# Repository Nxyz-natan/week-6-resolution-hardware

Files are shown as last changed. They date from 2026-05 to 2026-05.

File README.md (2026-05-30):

# RP2350A IMU Dev Board

A custom dev board built around the RP2350A microcontroller with an 
onboard MPU-6050 IMU for motion sensing, housed in a custom 3D printed case.

PCB Render:Screenshot 2026-05-29 at 9 38 06 PM

## How it works

The board uses a USB-C connector and an AMS1117-33 LDO to regulate 
5V down to 3.3V. The RP2350A runs with a 12MHz crystal oscillator and 
W25Q128 flash memory over QSPI. The MPU-6050 IMU connects over I2C on 
GPIO4 and GPIO5 for motion sensing. GPIO headers expose the remaining 
pins for external use.

KiCanvas Link: https://kicanvas.org/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

Case Design Link: https://app.shapr3d.com/p/ce0b803e-1716-4454-bb49-c60d17f44aa6

## Schematic

Schematic: Screenshot 2026-05-29 at 9 38 57 PM

## PCB

PCB: Screenshot 2026-05-29 at 9 39 11 PM

## Case

Case: Screenshot 2026-05-29 at 9 39 25 PM

## Bill of Materials

| Ref | Value  LCSC # |
|-----|---|
| U1 | RP2350A | C42411118 |
| U2 | W25Q128JVSIQ | C97521 |
| U3 | AMS1117-3.3 | C6186 |
| U4 | MPU-6050 | C24112 |
| R1, R2 | 5.1k 0603 | C2907044 |
| R3 | 1k 0603 | C22548 |
| R4, R5 | 27Ω 0603 | C137753 |
| R6, R7 | 10k 0603 | TBD |
| R8, R9 | 4.7k 0603 | C99782 |
| C1-C4 | 1uF 0603 | C15849 |
| C5-C11, C14-C18 | 100nF 0603  | C14663 |
| C12, C13 | 15pF 0603 | C1644 |
| Y1 | 12MHz Crystal SMD3225 | C9002 |
| J1 | USB-C TYPE-C-31-M-12 | C165948 |
| J2 | 1x04 Pin Header 2.54mm | C52016392 |
| J4 | 1x20 Pin Header 2.54mm | C50981 |
| J5 | 1x13 Pin Header 2.54mm  | C42372505 |
| SW1, SW2 | SW Push 6x6mm | C318884 |

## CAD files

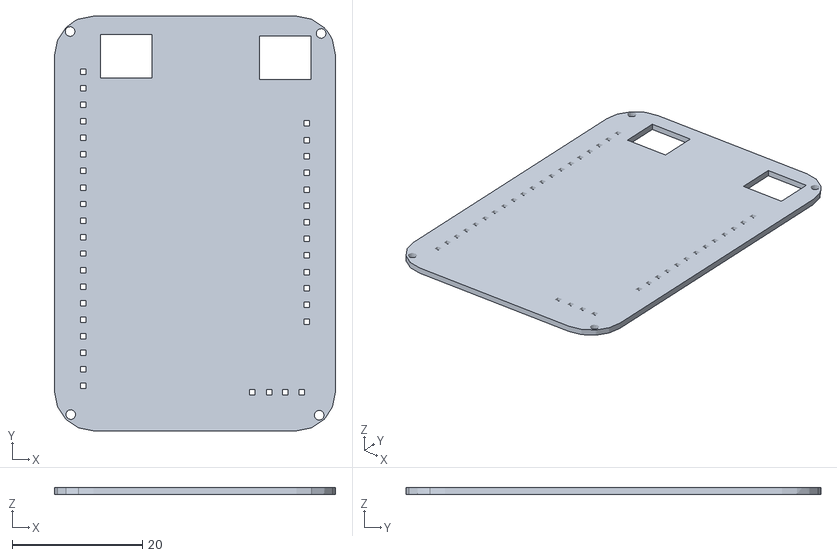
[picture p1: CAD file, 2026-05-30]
production/devboard lid.stl
43.2 x 63.8 x 1.00

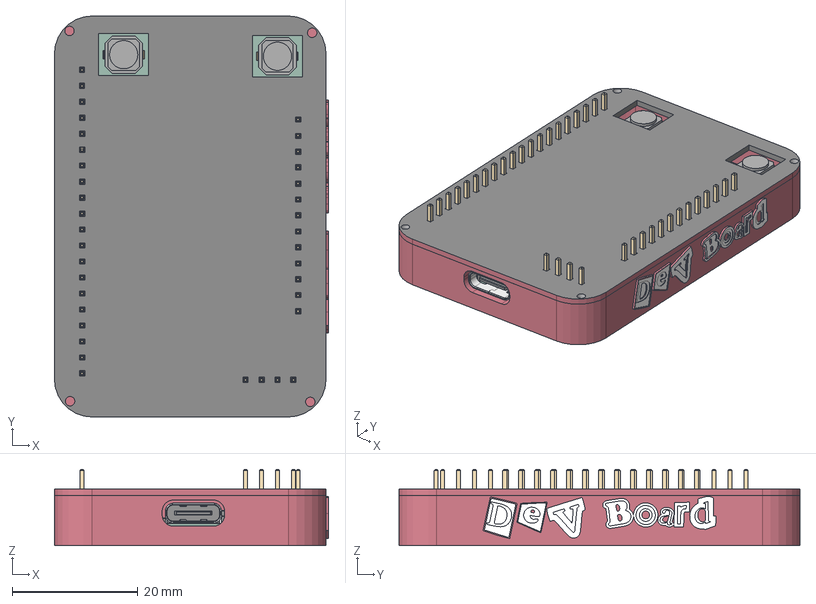
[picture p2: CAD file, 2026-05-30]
src/deboard case.step
43.6 x 63.8 x 12.1 mm
pin_1 x 2
pin_2 x 2
Pins
R_0603_1608Metric x 9
PinHeader_1x04_P2.54mm_Vertical
C_0603_1608Metric x 18
SOT-223
SOIC-8_L5.3-W5.3-H1.9-LS7.9-P1.27
PinHeader_1x13_P2.54mm_Vertical
RP2350A
Crystal_SMD_3225-4Pin_3.2x2.5mm
PinHeader_1x20_P2.54mm_Vertical
ConPins
PcbPins
Mold
Frame
week 6 resolution_PCB

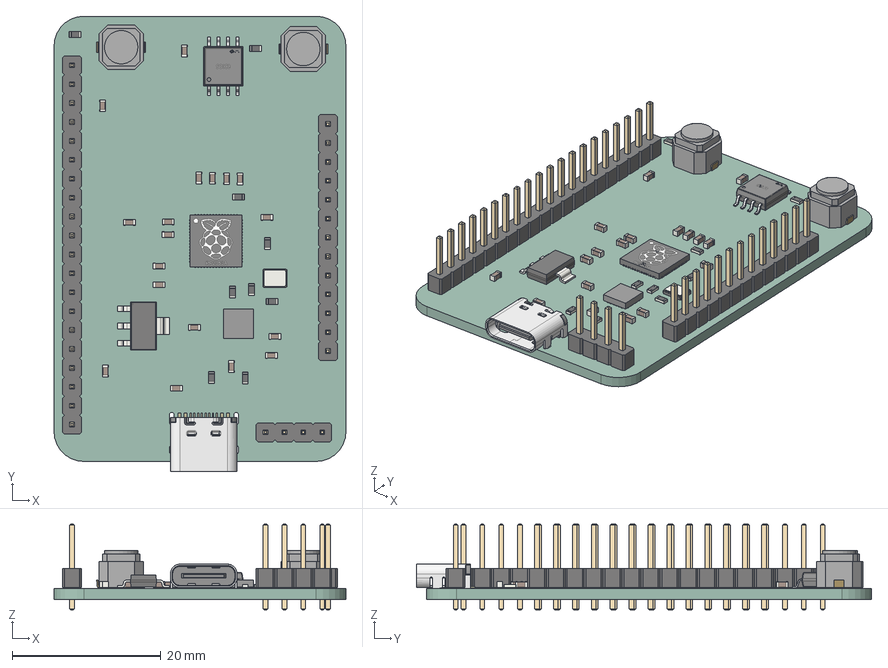
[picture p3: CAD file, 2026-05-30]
src/kicad/devboard pcb.step
39.2 x 61.2 x 11.5 mm
pin_1 x 2
pin_2 x 2
Pins
R_0603_1608Metric x 9
PinHeader_1x04_P2.54mm_Vertical
C_0603_1608Metric x 18
SOT-223
SOIC-8_L5.3-W5.3-H1.9-LS7.9-P1.27
PinHeader_1x13_P2.54mm_Vertical
RP2350A
Crystal_SMD_3225-4Pin_3.2x2.5mm
PinHeader_1x20_P2.54mm_Vertical
ConPins
PcbPins
Mold
Frame
week 6 resolution_PCB

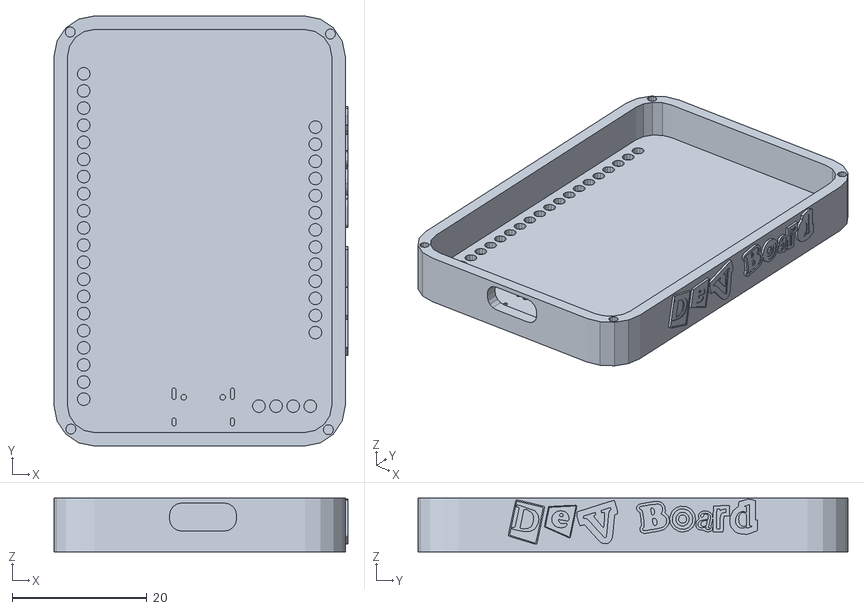
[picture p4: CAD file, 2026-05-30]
production/bottom cas devboard.stl
43.6 x 63.8 x 8.00

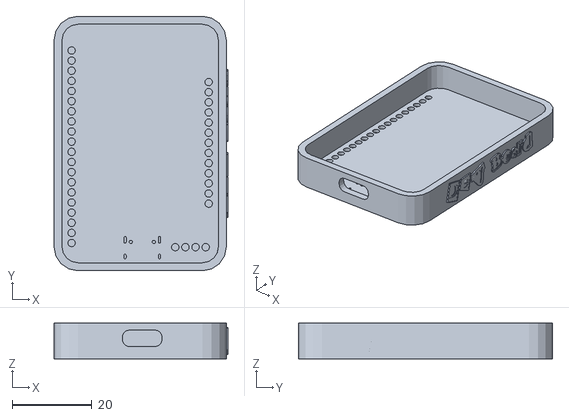
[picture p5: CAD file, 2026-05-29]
production/devboard case.stl
43.6 x 63.8 x 9.00

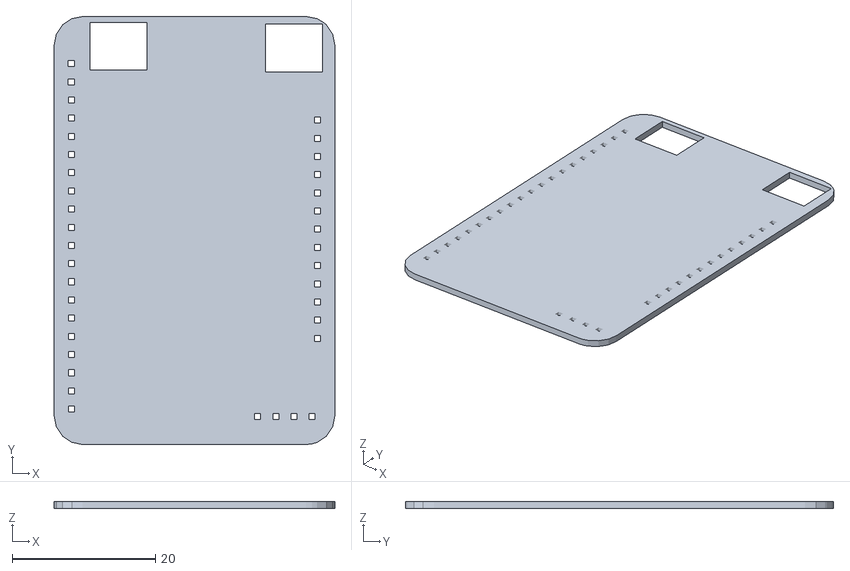
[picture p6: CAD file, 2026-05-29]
production/devboard top.stl
39.2 x 59.8 x 1.00

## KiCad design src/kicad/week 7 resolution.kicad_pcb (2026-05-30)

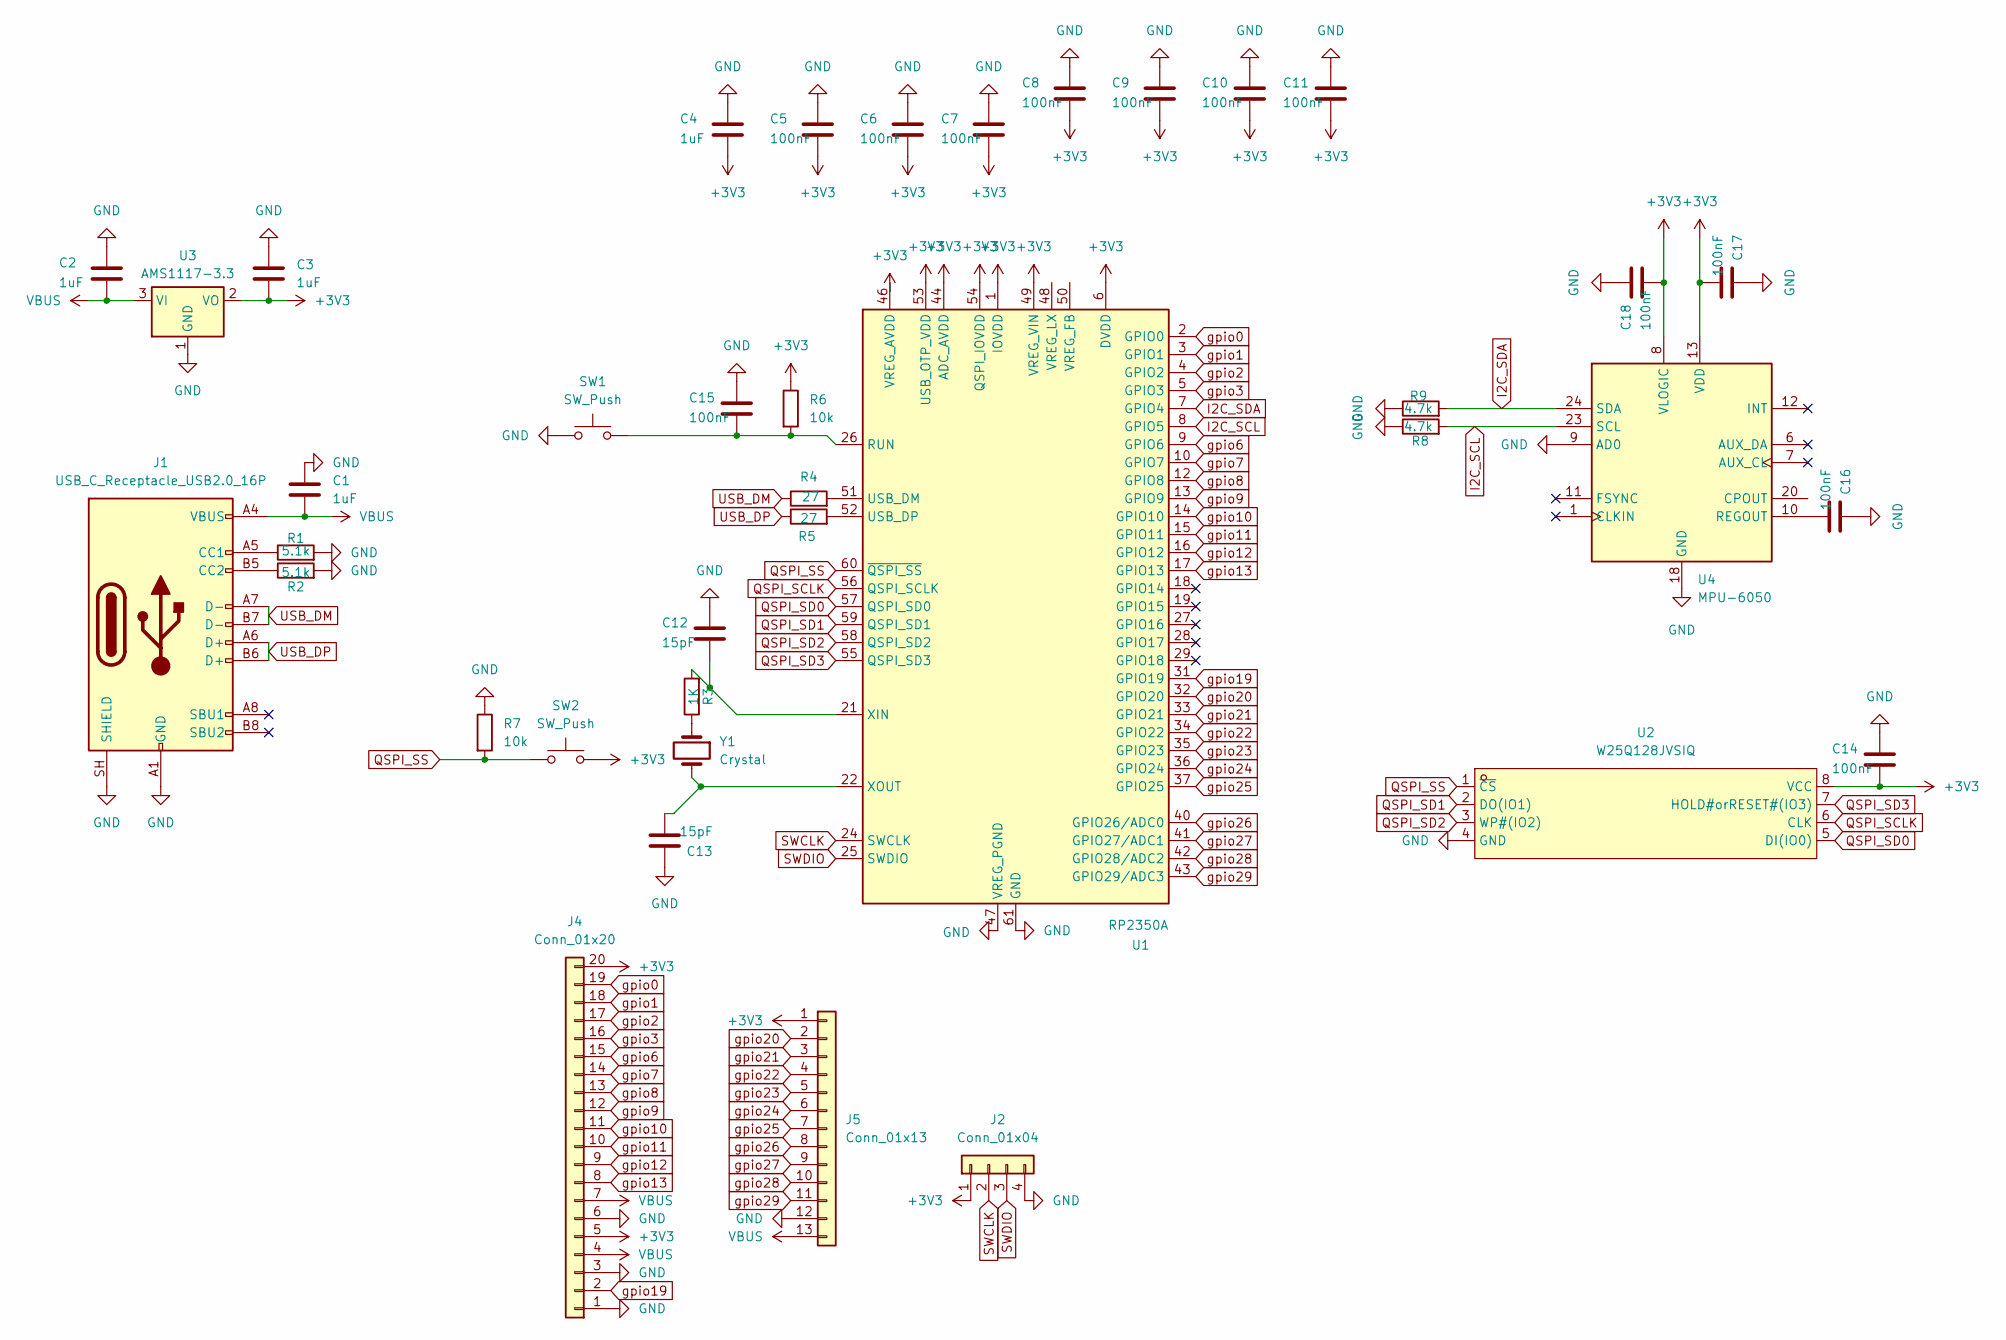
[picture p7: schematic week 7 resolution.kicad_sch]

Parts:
C1, C2, C3, C4: 1uF; C_0603_1608Metric
C5, C6, C7, C8, C9, C10, C11, C14, C15, C16, C17, C18: 100nF; C_0603_1608Metric
C12, C13: 15pF; C_0603_1608Metric
J1: USB_C_Receptacle_USB2.0_16P; USB_C_Receptacle_HRO_TYPE-C-31-M-12
J2: Conn_01x04; PinHeader_1x04_P2.54mm_Vertical
J4: Conn_01x20; PinHeader_1x20_P2.54mm_Vertical
J5: Conn_01x13; PinHeader_1x13_P2.54mm_Vertical
R1, R2: 5.1k; R_0603_1608Metric
R3: 1K; R_0603_1608Metric
R4, R5: 27; R_0603_1608Metric
R6, R7: 10k; R_0603_1608Metric
R8, R9: 4.7k; R_0603_1608Metric
SW1, SW2: SW_Push; SW_Push_1TS009xxxx-xxxx-xxxx_6x6x5mm
U1: RP2350A; QFN-60-1EP_7x7mm_P0.4mm_EP3.4x3.4mm
U2: W25Q128JVSIQ; SOIC-8_L5.3-W5.3-P1.27-LS8.0-BL; MPN W25Q128JVSIQ; LCSC Part C113767
U3: AMS1117-3.3; SOT-223-3_TabPin2
U4: MPU-6050; InvenSense_QFN-24_4x4mm_P0.5mm
Y1: Crystal; Crystal_SMD_3225-4Pin_3.2x2.5mm

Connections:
+3V3: C3.2, C4.2, C5.2, C6.2, C7.2, C8.2, C9.2, C10.2, C11.2, C14.2, C17.2, C18.2, J2.1, J4.5, J4.20, J5.1, R6.1, SW2.2, U1.1 (IOVDD), U1.6 (DVDD), U1.11 (IOVDD), U1.20 (IOVDD), U1.23 (DVDD), U1.30 (IOVDD), U1.38 (IOVDD), U1.39 (DVDD), U1.44 (ADC_AVDD), U1.45 (IOVDD), U1.46 (VREG_AVDD), U1.49 (VREG_VIN), U1.53 (USB_OTP_VDD), U1.54 (QSPI_IOVDD), U2.8 (VCC), U3.2 (VO), U4.8 (VLOGIC), U4.13 (VDD); also elsewhere on the board
GND: C1.1, C2.1, C3.1, C4.1, C5.1, C6.1, C7.1, C8.1, C9.1, C10.1, C11.1, C12.1, C13.1, C14.1, C15.1, C16.1, C17.1, C18.1, J1.A1 (GND), J1.A12 (GND), J1.B1 (GND), J1.B12 (GND), J1.SH (SHIELD), J2.4, J4.1, J4.3, J4.6, J5.12, R1.2, R2.2, R7.1, R8.1, R9.1, SW1.1, U1.47 (VREG_PGND), U1.61 (GND), U2.4 (GND), U3.1 (GND), U4.9 (AD0), U4.18 (GND); also elsewhere on the board
I2C_SCL: R8.2, U1.8 (GPIO5), U4.23 (SCL)
I2C_SDA: R9.2, U1.7 (GPIO4), U4.24 (SDA)
unnamed: J1.A5 (CC1), R1.1
unnamed: J1.B5 (CC2), R2.1
unnamed: R3.1, Y1.1
unnamed 7: C15.2, R6.2, SW1.2, U1.26 (RUN); also elsewhere on the board
unnamed: R4.2, U1.51 (USB_DM)
unnamed: R5.2, U1.52 (USB_DP)
unnamed: C16.2, U4.10 (REGOUT)
QSPI_SCLK: U1.56 (QSPI_SCLK), U2.6 (CLK)
QSPI_SD0: U1.57 (QSPI_SD0), U2.5 (DI(IO0))
QSPI_SD1: U1.59 (QSPI_SD1), U2.2 (DO(IO1))
QSPI_SD2: U1.58 (QSPI_SD2), U2.3 (WP#(IO2))
QSPI_SD3: U1.55 (QSPI_SD3), U2.7 (HOLD#orRESET#(IO3))
QSPI_SS: R7.2, SW2.1, U1.60 (~QSPI_SS), U2.1 (~CS); also elsewhere on the board
SWCLK: J2.2, U1.24 (SWCLK)
SWDIO: J2.3, U1.25 (SWDIO)
USB_DM: J1.A7 (D-), J1.B7 (D-), R4.1
USB_DP: J1.A6 (D+), J1.B6 (D+), R5.1
VBUS: C1.2, C2.2, J1.A4 (VBUS), J1.A9 (VBUS), J1.B4 (VBUS), J1.B9 (VBUS), J4.4, J4.7, J5.13, U3.3 (VI)
gpio0: J4.19, U1.2 (GPIO0)
gpio1: J4.18, U1.3 (GPIO1)
gpio2: J4.17, U1.4 (GPIO2)
gpio3: J4.16, U1.5 (GPIO3)
gpio6: J4.15, U1.9 (GPIO6)
gpio7: J4.14, U1.10 (GPIO7)
gpio8: J4.13, U1.12 (GPIO8)
gpio9: J4.12, U1.13 (GPIO9)
gpio10: J4.11, U1.14 (GPIO10)
gpio11: J4.10, U1.15 (GPIO11)
gpio12: J4.9, U1.16 (GPIO12)
gpio13: J4.8, U1.17 (GPIO13)
gpio19: J4.2, U1.31 (GPIO19)
gpio20: J5.2, U1.32 (GPIO20)
gpio21: J5.3, U1.33 (GPIO21)
gpio22: J5.4, U1.34 (GPIO22)
gpio23: J5.5, U1.35 (GPIO23)
gpio24: J5.6, U1.36 (GPIO24)
gpio25: J5.7, U1.37 (GPIO25)
gpio26: J5.8, U1.40 (GPIO26/ADC0)
gpio27: J5.9, U1.41 (GPIO27/ADC1)
gpio28: J5.10, U1.42 (GPIO28/ADC2)
gpio29: J5.11, U1.43 (GPIO29/ADC3)
xin: C12.2, R3.2, U1.21 (XIN)
xout: C13.2, U1.22 (XOUT), Y1.2

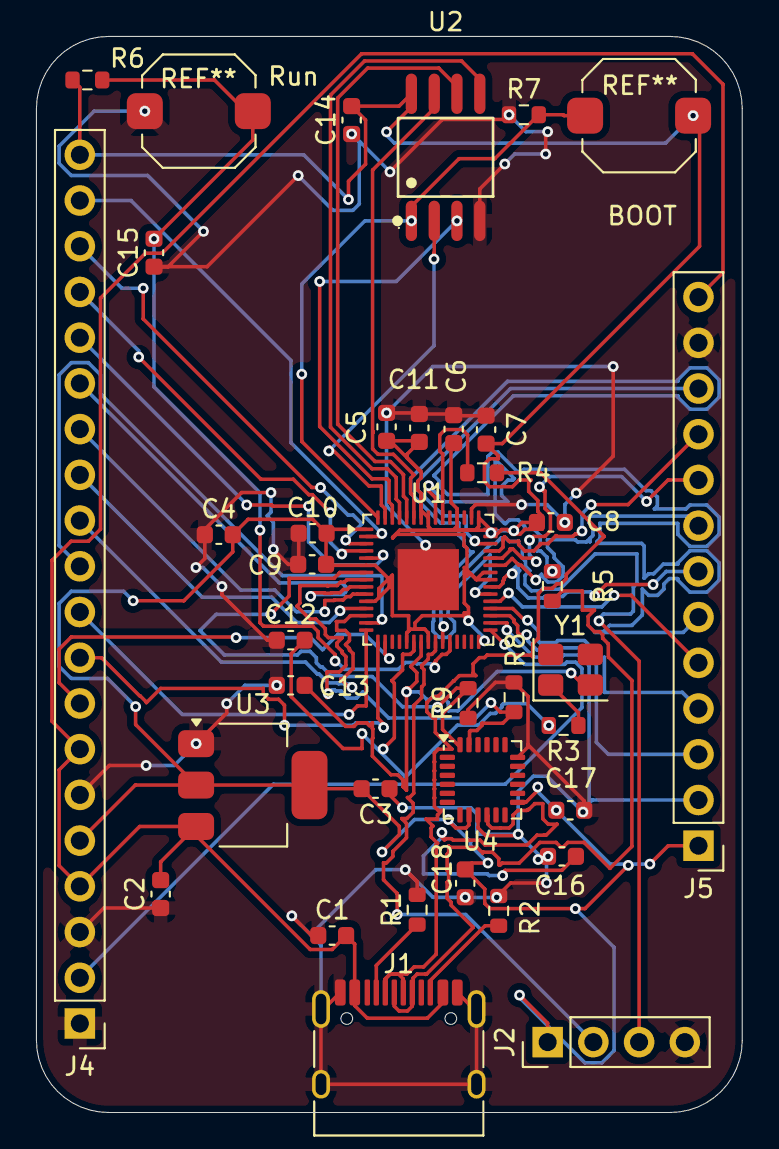
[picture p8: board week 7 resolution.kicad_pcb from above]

Board: 2 copper layers, 39.2 x 59.8 mm, 38 parts (0 on the bottom side), 47 nets.

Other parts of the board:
BOOT: SW_Push; SW_Push_1TS009xxxx-xxxx-xxxx_6x6x5mm
Run: SW_Push; SW_Push_1TS009xxxx-xxxx-xxxx_6x6x5mm

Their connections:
+3V3: BOOT.2; also elsewhere on the board
GND: Run.1; also elsewhere on the board
unnamed 7: Run.2; also elsewhere on the board
QSPI_SS: BOOT.1; also elsewhere on the board

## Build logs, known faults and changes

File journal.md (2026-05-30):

# RP2350A IMU Dev Board

[Preface] I am building a custom dev board around the RP2350A because 
I wanted to design my own PCB from scratch with an onboard IMU for 
motion sensing.

## May 27 - Schematic Design and pcb

Today I worked on the full schematic in KiCad. I started with the 
power section using a USB-C connector and an AMS1117-33 LDO to bring 
5V down to 3.3V. Then I wired up the RP2350A with:

- Decoupling caps on all power pins
- A 12MHz crystal oscillator
- W25Q128 flash memory over QSPI
- USB data lines with 27Ω series resistors
- A reset button on the RUN pin
- A boot button on QSPI_SS
- An MPU-6050 IMU over I2C on GPIO4 and GPIO5
- Two GPIO headers to expose pins

I ran into an issue with the USB-C wiring where I put the 51k CC 
resistors on the wrong pins. I researched how USB-C CC pins work and 
found they handle power negotiation with the host, so I moved them to 
the correct pins and it worked fine after that.

I also had trouble routing the PCB since everything was very tight and 
I couldn't manage to wire 4 GPIO pins. I went back to the schematic 
and reassigned those pins to VBUS, GND, and 3V3 instead which made 
routing much cleaner.

### Time Spent: 4 Hours

## May 27 - Case Design

Today I designed a case for the dev board in Shapr3D.

I started by exporting the PCB as a STEP file from KiCad and importing 
it into Shapr3D to use as a reference for the case dimensions. I 
designed the case in two parts  a bottom tray and a top lid  with 
1.5mm screw holes in each corner so the two pieces can be fastened 
together with M2 screws.

I added cutouts for the USB-C port and GPIO headers so they remain 
accessible when the case is closed. I also added "Dev Board" text on 
the bottom of the case using the emboss tool to give it a personal touch.

The main challenge was getting the screw holes to fit without cracking 
the walls since the case walls were thin. I reduced the hole size to 
1.5mm and placed them at the corners where the walls were thickest.

### Time Spent: 2 Hours

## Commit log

2026-05-28 Fix image links and add details on PCB design
    Updated README.md with corrected image links and additional details about the PCB design and USB-C wiring issues.
2026-05-30 Rename week 6/week 6 resolution.kicad_pcb to src/kicad/week 7 resolution.kicad_pcb
    [week 7 resolution.kicad_pcb]
2026-05-30 Rename week 6/week 6 resolution.kicad_pro to src/kicad/week 7 resolution.kicad_pro
2026-05-30 Add week 7 resolution schematic file
    [week 7 resolution.kicad_sch]
2026-05-30 update BOM format
2026-05-30 Rename devboard case.stl to devboard case.stl
    [devboard case.stl]
2026-05-30 Rename devboard top.stl to devboard top.stl
    [devboard top.stl]
